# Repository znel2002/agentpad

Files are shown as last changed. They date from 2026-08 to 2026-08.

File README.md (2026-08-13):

# AgentPad

A 9-key macropad + rotary encoder + OLED for driving **AI coding agents** — Claude Code, Codex CLI, and Cursor. Firmware-native (no host daemon), vendor-neutral, with a per-tool **LAYER** key instead of app-detection. Built for **Hack Club Hackpad**.

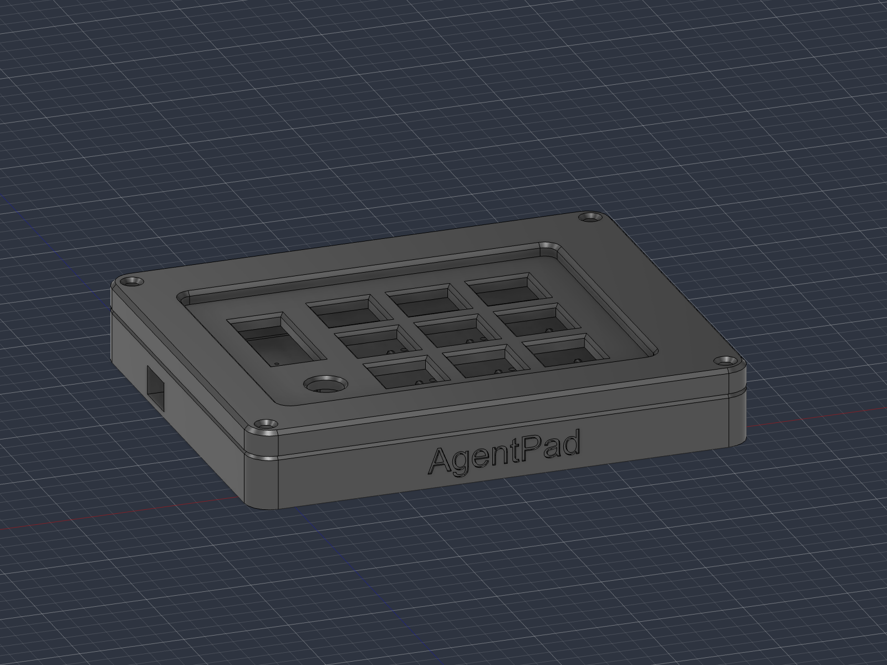
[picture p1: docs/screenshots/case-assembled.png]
AgentPad — real PCB in the 3D-printed case


## What it does

Nine keys mapped to the actions you hit dozens of times an hour when driving an agent, plus a rotary dial and a status screen:

| | | |
|---|---|---|
| **STOP** (interrupt) | **YES** (approve) | **NO** (reject) |
| **PLAN** (mode toggle) | **NEW** (`/clear`) | **TALK** (push-to-talk) |
| **RUN** (test/last cmd) | **COMPACT** (`/compact`) | **LAYER** (switch tool) |

- **Encoder** — turn = model / reasoning-effort dial.
- **OLED** — shows the active tool profile + mode.
- **LAYER key** — cycles per-tool keymaps: **Claude Code → Codex → Cursor → shell**. Each key sends that tool's real shortcut; hold-LAYER reaches secondary actions (accept-edit, reject-edit, resume, background). No daemon, no app-detection.

Full keymap + pin map: [docs/DESIGN-SPEC.md](docs/DESIGN-SPEC.md). Keymap logic is unit-tested: [Firmware/tests/sim_keymap.py](Firmware/tests/sim_keymap.py).

## Hardware

- **MCU:** Seeed XIAO RP2040 (all 11 GPIO used)
- **Keys:** 9× MX in a 3×3 diode matrix (9× 1N4148, COL2ROW)
- **Encoder:** 1× EC11 (turn-only)
- **Display:** 1× 0.91" SSD1306 OLED (I2C)
- **Firmware:** KMK (CircuitPython)
- **RGB:** deferred to v2 (v1 ships without LEDs)

## Renders & proof

**Exploded — top plate / PCB / bottom tray**
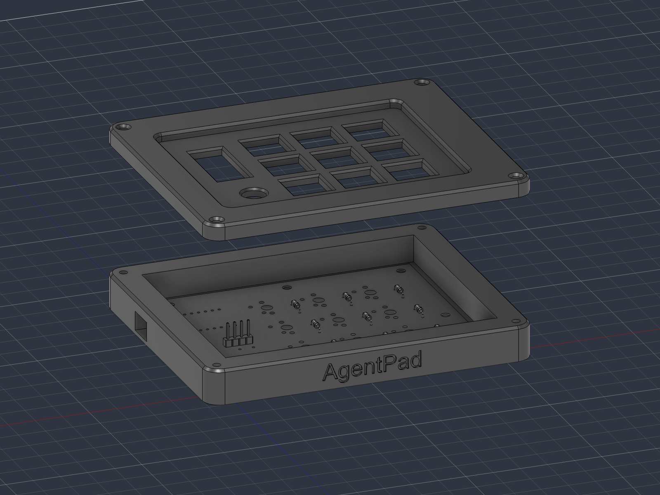
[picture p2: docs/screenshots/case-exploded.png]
Exploded assembly


**Schematic**
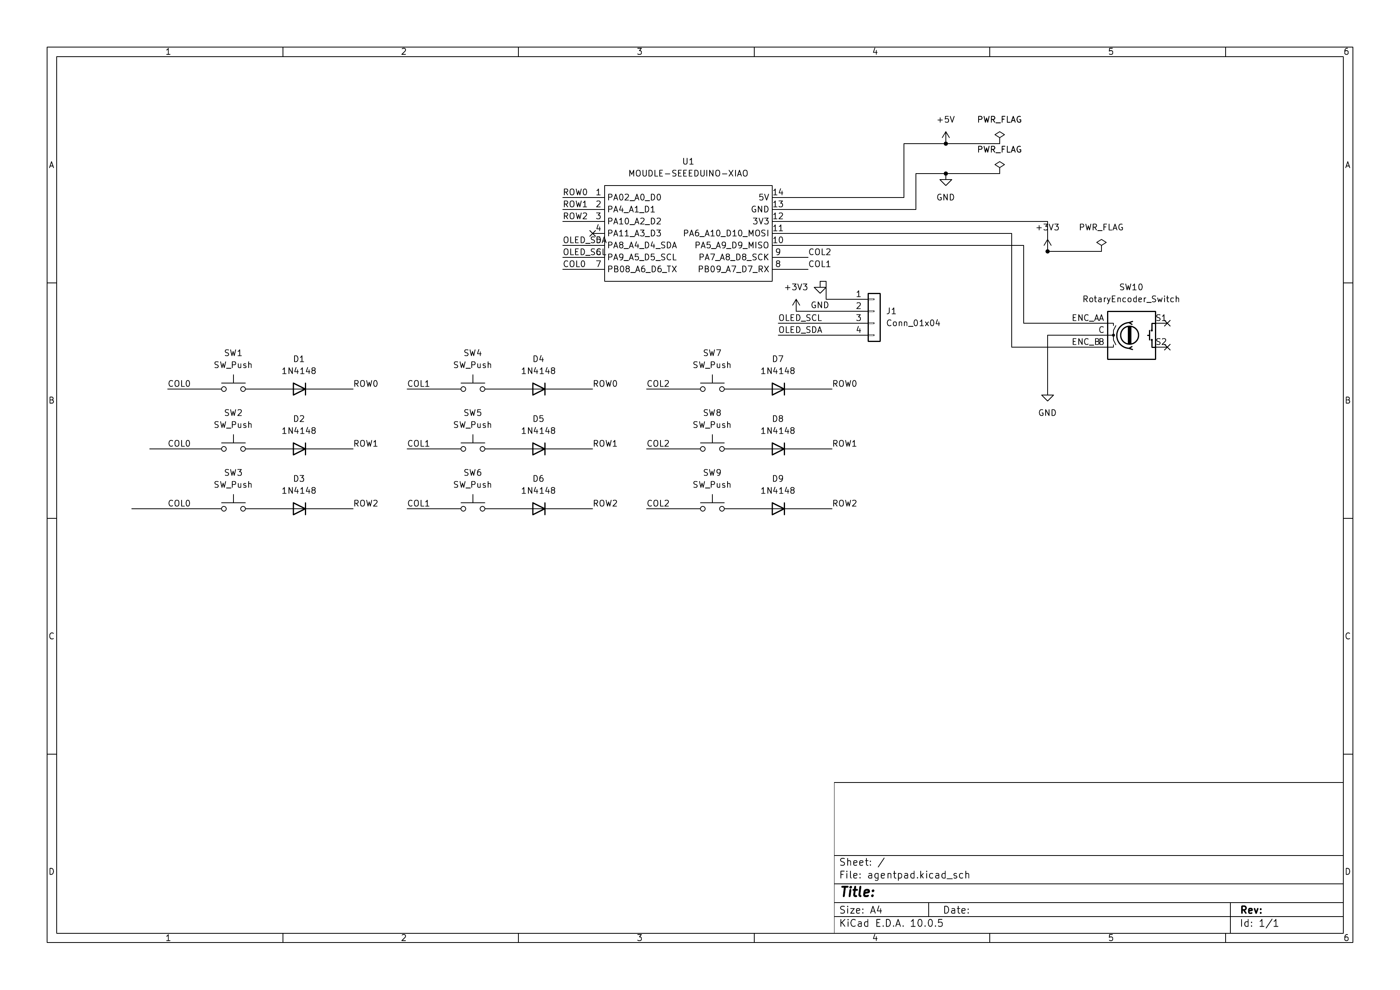
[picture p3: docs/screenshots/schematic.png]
Schematic


**PCB — DRC passes with 0 errors**
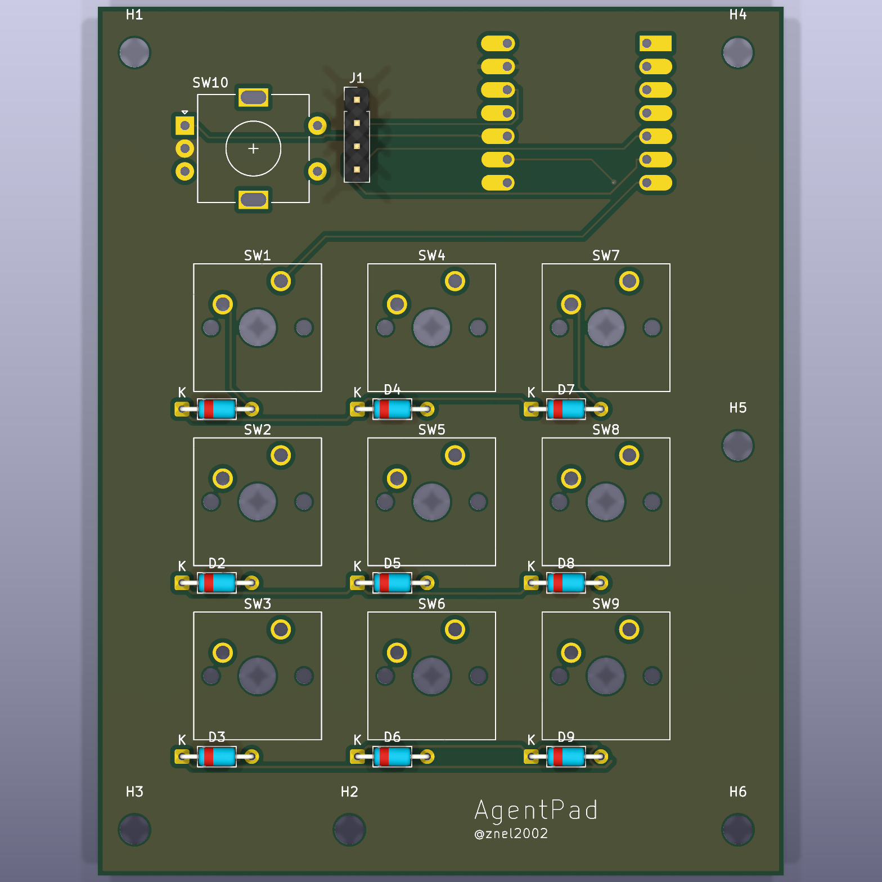
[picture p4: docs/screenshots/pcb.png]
PCB


## Bill of Materials

All parts come from the free Hackpad kit (nothing self-sourced):

| Part | Qty | Notes |
|---|---|---|
| Seeed XIAO RP2040 | 1 | microcontroller |
| 1N4148 diode | 9 | switch matrix, COL2ROW, `D_DO-35_SOD27_P7.62mm` |
| MX-style switch | 9 | solder-in, 3×3 grid @ 19.05 mm |
| EC11 rotary encoder | 1 | model / effort dial |
| 0.91" OLED (SSD1306) | 1 | I2C, pin order GND-VCC-SCL-SDA |
| DSA blank keycap | 9 | color/legend via a printed card |
| M3 screw | 4 | lid → base corner posts |

## Repo structure

```
CAD/         agentpad-case.f3d (Fusion source), agentpad_assembly.step/.3mf (case + real PCB), board STEP
PCB/         KiCad project — schematic, board (DRC 0 errors), Hack Club care-package libs
Firmware/    KMK source (kmk/main.py) + keymap simulation test
production/  gerbers.zip, top_plate.stl, bottom_tray.stl, main.py
docs/        DESIGN-SPEC, BUILD-PLAN, screenshots
```

## Firmware (KMK)

Flash CircuitPython to the XIAO, copy the KMK `kmk/` folder + libs + [`Firmware/kmk/main.py`](Firmware/kmk/main.py) to the `CIRCUITPY` drive. Details + per-layer keystroke tables: [Firmware/README.md](Firmware/README.md).

## Case

3D-printed two-part sandwich — **top lid + bottom base** — designed in **Autodesk Fusion** ([CAD/agentpad-case.f3d](CAD/agentpad-case.f3d)) around the exact PCB (imported as STEP). Both parts print flat with no supports.

- **Lid:** recessed key well inside a raised bezel; 9 switch cutouts with chamfered mouths, an encoder hole, and an OLED window; rounded R6 corners.
- **Base:** holds the PCB on corner posts; USB-C exits a slot in the side wall; **AgentPad** engraved on the front wall; matching R6 corners and chamfered top edge.
- **Assembly:** 4× M3 screws through the lid into the base's corner posts.

Fit is verified against the real board geometry — switch cutouts sit exactly on the switch stems, and screw holes align to the base bosses.

## License

MIT — see notes; the vendored Hack Club care package under `PCB/lib/` retains its own license.

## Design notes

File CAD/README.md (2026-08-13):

# CAD — AgentPad case

Two-part 3D-printed sandwich (top lid + bottom base), designed in **Autodesk Fusion**
around the exact PCB. The board is imported as STEP and every cutout is placed on the
real switch/encoder/OLED/mounting geometry.

## Files
- `agentpad-case.f3d` — Fusion source (editable), the case + inserted PCB reference.
- `agentpad_assembly.step` / `agentpad_assembly.3mf` — full assembly (case + real PCB).
- `agentpad-board.step` — the KiCad board export.
- `agentpad-board-origin.step` — the same board parked at the origin (used as the Fusion import reference).
- Printable parts live in [`../production/`](../production/): `top_plate.stl` (lid), `bottom_tray.stl` (base).

## Design
- **Outer size:** 120 × 100 mm (both parts match). Rounded corners R6.
- **Lid:** 3 mm plate + 4 mm raised bezel around a recessed key well. 9× 14 mm switch
  cutouts with chamfered mouths, Ø8.5 encoder hole, OLED window, 4× M3 clearance holes.
- **Base:** ~13 mm tall tray holding the PCB; USB-C slot in the side wall; `AgentPad`
  engraved on the front wall; 4 corner posts for the screws.
- **Assembly:** 4× M3 screws, lid → base corner posts.

## Print notes
- Both parts print flat, **no supports**.
- Print tolerance ~0.2 mm between mating parts.
- **Verify before printing** (physical modules): the OLED window and USB-C opening
  size/position, and the encoder hole diameter vs your knob.

## Hard limits
- Case ≤ **200 × 200 × 100 mm**, **3D-printed only** (no laser/acrylic parts). ✔

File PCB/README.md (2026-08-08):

# PCB — AgentPad

KiCad source for the AgentPad board. Design locked in
[../docs/DESIGN-SPEC.md](../docs/DESIGN-SPEC.md).

## Before you start
1. KiCad **10.0.5** is installed. Its libraries are forward-compatible, so the
   care package (authored on an older version) loads fine — no version issue.
2. Download + install the libraries here:
   - **Care package** (XIAO symbol + footprints): https://github.com/hackclub/hackpad/releases/tag/v0.1-bugfix → `kicad_care_package.zip`
   - XIAO footprints (backup): https://github.com/Seeed-Studio/OPL_Kicad_Library
   - MX switch footprints: https://github.com/ai03-2725/MX_V2
   - Rotary encoder: https://kicad.github.io/footprints/Rotary_Encoder
   - 0.91" OLED (4-pin): https://github.com/gorbachev/KiCad-SSD1306-0.91-OLED-4pin-128x32.pretty
   - The `.sym` files are symbol libs; the `.pretty` folders are footprint libs
     (Preferences → Manage Symbol/Footprint Libraries → add).
3. **Reference board** — the guide author's macropad (OLED + encoder + matrix +
   SK6812, closest to ours): https://github.com/hackclub/hackpad/tree/clean/extras/orpheuspad
4. Learn the flow: ai03's PCB guide https://wiki.ai03.com/books/pcb-design
5. Build the 3-key tutorial board first (XIAO symbol = `MODULE-SEEEDUINO-XIAO`,
   switches = `SW_Push`) to validate the toolchain, then extend to this net map.

## Net map — XIAO RP2040 pad → net (all 11 GPIO used)

| Pad | GPIO | Net |
|---|---|---|
| D0 | GP26 | ROW0 |
| D1 | GP27 | ROW1 |
| D2 | GP28 | ROW2 |
| D3 | GP29 | LED_DIN (SK6812 chain data-in) |
| D4 | GP6 | OLED_SDA (I2C) |
| D5 | GP7 | OLED_SCL (I2C) |
| D6 | GP0 | COL0 |
| D7 | GP1 | COL1 |
| D8 | GP2 | COL2 |
| D9 | GP4 | ENC_A |
| D10 | GP3 | ENC_B |
| 3V3 | — | OLED VCC |
| **5V** | — | **all SK6812 VCC** (the LEDs are 5V parts, per the Hackpad add-components page) |
| GND | — | matrix/encoder commons, OLED GND, all SK6812 GND |

> Data logic stays at the XIAO's 3.3V; SK6812 run their VCC at 5V (the XIAO's 5V/USB
> pad). This is how the kit is designed — do not put SK6812 VCC on 3V3.

## Exact symbols / footprints (confirmed on hackpad.hackclub.com/add-components)

Verified against the unpacked care package in `lib/kicad_care_package/`. The care
package holds **only** the XIAO + SK6812; everything else is a KiCad built-in lib.

| Part | Symbol | Footprint | Source |
|---|---|---|---|
| XIAO RP2040 | `MOUDLE-SEEEDUINO-XIAO` *(sic — typo is in the file, search it literally)* | `XIAO-Generic-Hybrid-14P-2.54-21X17.8MM` | care package |
| SK6812 MINI-E | `SK6812MINI-E` | `SK6812MINI-E_fixed` | care package |
| MX switch | `SW_Push` | `ai03-2725/MX_V2` (or KiCad `Button_Switch_Keyboard`) | KiCad / MX_V2 |
| Diode 1N4148 | `D` | `Diode_THT:D_DO-35_SOD27_P7.62mm_Horizontal` (don't go shorter) | KiCad built-in |
| EC11 encoder | `RotaryEncoder_Switch` | `RotaryEncoder_Alps_EC11E-Switch_Vertical_H20mm` | KiCad built-in |
| 0.91" OLED | 4-pin header (`Connector_Generic`) | `PinHeader_1x04_P2.54mm_Vertical` | KiCad built-in |

No pull-up resistors anywhere — the RP2040 has internal pull-ups (kit relies on this).

## Matrix (3×3, 9 keys)
- One **1N4148** (onsemi) per key, all the **same orientation (COL2ROW)**. Wrong
  diode direction is the #1 beginner failure — verify against the KMK config
  (`Firmware/kmk/main.py`, `diode_orientation = COL2ROW`). The physical diode has
  a **black bar** marking the cathode.
- Footprint `Diode_THT:D_DO-35_SOD27_P7.62mm_Horizontal`.
- Keys map row-major to the keymap: R1C1..R1C3, R2C1..R2C3, R3C1..R3C3.

## Encoder (EC11E, 20 mm D-shaft)
- Symbol `RotaryEncoder_Switch`, footprint `RotaryEncoder_Alps_EC11E-Switch_Vertical_H20mm`.
- A → ENC_A (D9), B → ENC_B (D10), common → GND. No pull-ups needed.
- **Turn-only config:** the footprint includes the push-switch pins — leave them
  **unconnected**. Keeping the pads means an 8-key clickable variant is possible
  later without a respin.

## OLED (0.91" 128×32 SSD1306, I2C @ 0x3C)
- Footprint = plain **2.54 mm 4-pin header** (the module has a standard header;
  no special footprint needed).
- **Pin order GND-VCC-SCL-SDA** — match it exactly (online pinouts vary).
- SDA→D4, SCL→D5, VCC→3V3, GND→GND. No pull-ups needed.

## SK6812 MINI-E chain (20 LEDs, 1 data line)
- Footprint `SK6812MINI-E` from the care package (**not** `SK6812MINI`; symbol +
  both footprints must say MINI-E).
- 4 pins: VCC (**5V**), GND, DIN, DOUT. D3 → LED1 DIN; each DOUT → next DIN; chain all 20.
- **Orientation: the notch/cut is on the bottom-right corner** — wrong rotation and
  the LEDs won't light. Keep every LED the same way.
- 9 per-key (under each switch) + up to 11 case underglow.
- Keep the data trace from the XIAO to LED1 short.

## Mounting holes (from the Hackpad resources page)
- Use KiCad's **M3 mounting-hole footprint** — NOT Edge.Cuts.
- 6 holes to match the 6× M3 screws / heatset inserts.
- For the OLED, a plain **4-pin header footprint** is fine (order GND-VCC-SCL-SDA).

## Routing tips (from the resources page)
- Try to route everything on **one layer** first; only drop to the 2nd layer to
  avoid a big loop. Keeps the board clean.
- After routing: **Tools → Cleanup Tracks & Vias** (press "Build changes" twice).
- Export the PCB to PDF and print 1:1 to sanity-check physical measurements.

## Preflight before ordering
- [ ] Board ≤ 100 × 100 mm, **2 layers**.
- [ ] `AgentPad` on the silkscreen.
- [ ] 6× M3 mounting-hole footprints placed.
- [ ] **DRC → 0 errors** (reviewers check this).
- [ ] Export gerbers → `../production/gerbers.zip`.
- [ ] Order JLCPCB immediately after DRC is clean.

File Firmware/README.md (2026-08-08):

# Firmware — AgentPad (KMK)

KMK (CircuitPython) firmware. Keymap + pin map locked in
[../docs/DESIGN-SPEC.md](../docs/DESIGN-SPEC.md). Entry point: [kmk/main.py](kmk/main.py).

## Flash setup (XIAO RP2040)
1. **CircuitPython:** double-tap the XIAO reset to enter bootloader (RPI-RP2
   drive), drop the CircuitPython `.uf2` for the Seeed XIAO RP2040
   (https://circuitpython.org/board/seeeduino_xiao_rp2040/). It reboots as a
   `CIRCUITPY` drive.
2. **KMK:** clone https://github.com/KMKfw/kmk_firmware and copy its `kmk/`
   folder to `CIRCUITPY/`.
3. **Libraries** (into `CIRCUITPY/lib/`, from the Adafruit CircuitPython bundle):
   - `neopixel.mpy` — per-key RGB
   - `adafruit_displayio_ssd1306.mpy` + `adafruit_display_text/` — OLED
     (displayio is built into CircuitPython on RP2040)
4. Copy [kmk/main.py](kmk/main.py) to `CIRCUITPY/main.py`. It runs on boot.

## Test order (before the PCB arrives)
Breadboard the XIAO and validate incrementally — comment out blocks in `main.py`:
1. Matrix scan (press a key across a row/col jumper → keystroke appears).
2. Encoder turn.
3. One SK6812 lights.
4. OLED prints text.

## Status
- Matrix, encoder, layers, hold-LAYER FN, static per-key RGB, OLED splash: scaffolded.
- **TODO:** finalize Codex / Cursor / shell keystrokes; verify the layer-cycle key
  on your KMK version (see the comment in `main.py`); optional live LED feedback.

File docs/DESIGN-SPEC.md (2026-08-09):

# AgentPad — Hardware & UX Design Spec (v1)

Status: **v1 PCB complete, DRC 0 errors.** This is the buildable design the PCB,
case, and firmware are cut from.

> **v1 ships without RGB LEDs.** The SK6812 reverse-mount footprint (with its
> built-in board cutout) could not pass edge-clearance DRC, and RGB is not
> required by Hackpad (the reference board barely used LEDs). v1 = 9 switches +
> encoder + OLED. **RGB (per-key / underglow) is deferred to v2** with a proper
> LED footprint.

---

## 1. Locked decisions

| Decision | Value | Why |
|---|---|---|
| Name (branding) | **AgentPad** | On PCB silkscreen + top plate (Hackpad requires it) |
| MCU | Seeed XIAO RP2040 | Required by Hackpad; **11 usable GPIO** is the binding constraint |
| Config | **9 keys (3×3) + 1 EC11 encoder + 0.91" OLED + SK6812 RGB** | Only kit-only config that keeps screen + dial + per-key RGB |
| Encoder | **1, turn-only** (effort/model dial, live-apply) | 2nd encoder would force dropping the OLED; click would cost the 9th key |
| Firmware | **KMK** (CircuitPython) first, QMK fallback | Fastest iteration for a Python dev; no compile step |
| Tool layers | **4**: Claude Code · Codex · Cursor · shell | Vendor-neutral is the whole differentiator |
| PCB | 2-layer, ≤100×100 mm, **green** soldermask | Cheapest/fastest fab; DRC must pass 0 errors |
| Legends | **RGB color-coding + printed legend card** | Kit ships blank DSA caps; color is the legend |
| Case | 3D-printed sandwich, 6× M3 into heatset inserts, ≤200×200×100 mm | Kit + rules |

---

## 2. Pin budget (all 11 GPIO used)

RGB chains on one data wire regardless of LED count, so it costs 1 pin for all
20 LEDs. The rest divides as:

| Function | Pins | XIAO pads |
|---|---|---|
| Key matrix 3×3 (3 rows + 3 cols) | 6 | rows D0/D1/D2 (GP26/27/28), cols D6/D7/D8 (GP0/1/2) |
| Encoder A/B | 2 | D9/D10 (GP4/GP3) |
| OLED I2C (SDA/SCL) | 2 | D4/D5 (GP6/GP7) |
| SK6812 RGB data | 1 | D3 (GP29) |
| **Total** | **11** | D0–D10 fully allocated |

- Matrix diode direction: one 1N4148 per key (9 used of 20). Pick **COL2ROW** and
  keep every diode the same orientation (the #1 beginner failure). Confirm the
  direction against the KMK/QMK matrix config before ordering.
- OLED footprint pin order is **GND-VCC-SCL-SDA** (kit spec) — the PCB must match.
- Encoder is turn-only in this config (no matrix node free for the push). A
  clickable encoder is available only by dropping to 8 keys.

---

## 3. Keymap

9 physical keys in a fixed 3×3 grid. Each **layer** = one tool profile; the same
key sends that tool's equivalent keystroke. The Claude Code column is the
reference binding; the other three fill the same slots (finalized against each
tool's current shortcuts at firmware time).

| Pos | Key | Purpose | Claude Code keystroke |
|---|---|---|---|
| R1C1 | **STOP** | Interrupt the run, don't kill the session | `Esc` |
| R1C2 | **YES** | Approve / accept the pending prompt | `Enter` |
| R1C3 | **NO** | Reject / decline | `n` |
| R2C1 | **PLAN** | Cycle permission / plan mode | `Shift+Tab` |
| R2C2 | **NEW** | Clear context, fresh session | `/clear⏎` |
| R2C3 | **TALK** | Push-to-talk dictation (momentary, active while held) | hold `Space` |
| R3C1 | **RUN** | Fire test / last command | `npm test⏎` (configurable) |
| R3C2 | **COMPACT** | Compact the context window | `/compact⏎` |
| R3C3 | **LAYER** | **Tap** = cycle tool profile · **Hold** = FN modifier | — |

**Encoder:** turn = reasoning-effort / model dial, applies live; OLED shows the
new level.

**Hold-LAYER secondary actions** (recover the Tier-2/3 actions without more keys):
- Hold LAYER + **YES** = accept edit/diff
- Hold LAYER + **NO** = reject edit/diff
- Hold LAYER + **NEW** = resume session (`/resume⏎`)
- Hold LAYER + **RUN** = background task

Per-layer keystroke tables (Codex / Cursor / shell) → firmware appendix, TBD.

---

## 4. RGB scheme (20× SK6812, 1 data pin)

9 per-key LEDs + up to 11 case-underglow LEDs on the same chain (0 extra pins).

**Static per-key function color** (the legend):

| STOP 🔴 red | YES 🟢 green | NO 🟠 amber |
|---|---|---|
| **PLAN 🔵 blue** | **NEW 🟣 purple** | **TALK 🩵 cyan** (brightens while held) |
| **RUN ⚪ white** | **COMPACT teal** | **LAYER = active-tool color** |

**Layer identity** (LAYER key + underglow wash): Claude Code = amber · Codex =
green · Cursor = blue · shell = white.

**Feedback:** brief flash on key press.

Offline note: RGB encodes *local* state (layer, function, press). Live agent
status (idle/thinking/waiting) needs optional USB-serial feedback from the host —
**parked as a post-submission stretch.**

---

## 5. OLED (0.91", 128×32, SSD1306)

- Line 1: active tool profile — `CLAUDE CODE`
- Line 2: effort + mode — `effort: HIGH  ·  PLAN`
- Boot splash: `AgentPad` + logo.

Same offline caveat: the mode field tracks local PLAN/effort presses, it does not
read the host.

---

## 6. Physical layout

- 3×3 key grid on **19.05 mm** MX spacing. OLED top-left, encoder top-right on the
  strip above the grid. Estimated footprint ~70×90 mm (inside 100×100 mm).
- MX switches are **solder-in** (no hotswap sockets in kit).
- Sandwich case: top plate + PCB + bottom, 6× M3×16 screws into M3 heatset inserts.
- `AgentPad` branding on the top plate (recessed/embossed) **and** PCB silkscreen.
- Printed legend card / plate silkscreen keying the RGB colors to functions.

---

## 7. Open items before layout
- [ ] **Germany shipping** — ships from Burlington VT; the site never addresses
      international shipping. Confirm in #hackpad (the one real unknown).
- [ ] **Grant amount conflict** — the submitting page says **$15** for the PCB, the
      FAQ says **$10**. Confirm the current number in #hackpad. (Iron grant is $18,
      non-transferrable, both pages agree.)
- [ ] Confirm the kit's MX switch type (tactile vs linear) in #hackpad.
- [ ] Finalize Codex / Cursor / shell per-layer keystroke tables.
- [ ] Decide 9-key-turn-only vs 8-key-clickable-encoder (default: 9-key).
- [ ] Case color (decide at print time with Printing Legion).

---

## 8. Bill of materials (from the free kit)

| Part | Qty used / kit | Notes |
|---|---|---|
| Seeed XIAO RP2040 | 1 / 1 | |
| 1N4148 diode | 9 / 20 | one per key, COL2ROW |
| MX-style switch | 9 / 16 | solder-in |
| EC11 encoder | 1 / 2 | 2nd = solder backup |
| 0.91" OLED (SSD1306) | 1 / 1 | GND-VCC-SCL-SDA |
| SK6812 MINI-E LED | up to 20 / 20 | 9 per-key + underglow |
| DSA blank keycap | 9 / 16 | color-coded |
| M3×16 screw | 6 / 6 | |
| M3 heatset insert | 6 / 6 | |

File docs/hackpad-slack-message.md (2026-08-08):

# Draft message for #hackpad

Post this after joining. Confirms the three things public pages couldn't nail.
Edit the tone to taste.

---

> Hey! Starting a Hackpad build (a 9-key + encoder + OLED macropad for driving AI
> coding CLIs, XIAO RP2040, KMK). Three quick confirmations before I order a PCB:
>
> 1. **Shipping to Germany** 🇩🇪 — is the parts kit shipped to the EU/Germany, and is
>    the $15 PCB card-grant path available here?
> 2. **Grant amounts** — are the current grants $15 for the PCB and $18 for a
>    soldering iron? (FAQ still says $10 in one spot.)
> 3. **MX switches** — what switch type ships in the kit (tactile / linear /
>    clicky), so I can plan the feel?
>
> Thanks!

---

Record the answers in `docs/DESIGN-SPEC.md` §7 when they come back.

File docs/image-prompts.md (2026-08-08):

# Showcase image prompts (Gemini "Nano Banana" / 2.5 Flash Image)

For the README hero + ship post. Generate 3-4, pick the cleanest (OLED text,
screw count, and keycap spelling vary run to run). Top-down angles render the
keycap legends most reliably.

## Hero shot (with keycap legends)

```text
Professional product-showcase render of a custom mechanical macropad called
"AgentPad", a compact desktop keypad for controlling AI coding assistants.

FORM FACTOR: a small sandwich-style macropad, roughly 70 x 90 mm, made of a
3D-printed matte case (top plate + body) with a visible green PCB edge. Six small
M3 hex screws recessed into the top plate corners and mid-edges. Clean, minimal,
premium build quality.

TOP CONTROL STRIP (above the keys): on the LEFT a small 0.91-inch monochrome OLED
display (wide, short, blue-on-black) showing two crisp lines of text:
"CLAUDE CODE" on the first line and "effort: HIGH" on the second line. On the
RIGHT a knurled aluminium rotary encoder knob.

KEY LAYOUT: a 3x3 grid of nine white DSA-profile keycaps, evenly spaced on
19.05 mm pitch. Each cap has a short label printed in the center in a clean bold
black uppercase sans-serif font, and each key is lit from beneath by a per-key
RGB LED so the cap glows a distinct color. The nine keys, left-to-right and
top-to-bottom, are:
- Row 1: "STOP" glowing red, "YES" glowing green, "NO" glowing amber
- Row 2: "PLAN" glowing blue, "NEW" glowing purple, "TALK" glowing cyan
- Row 3: "RUN" glowing white, "COMPACT" glowing teal, "LAYER" glowing warm amber
All labels must be spelled exactly as written, correct spelling, legible and sharp.
A soft RGB underglow spills from beneath the case onto the surface below.

BRANDING: the word "AgentPad" printed cleanly in a modern sans-serif on the top
plate along the front edge, subtle and legible.

SCENE: three-quarter hero angle, slightly above eye level, on a dark matte desk
surface with a softly blurred dark studio background. Cinematic soft key light
with gentle rim lighting, realistic reflections on the keycaps and knob, shallow
depth of field, high detail, 4k product photography, sharp focus on the pad.

STYLE: clean tech-product marketing render, like a premium keyboard brand's
website hero image. Photorealistic. No hands, no extra objects, no clutter.

Aspect ratio 16:9.
```

## Variants
- **Top-down flat lay** (best for legible legends): replace the SCENE paragraph with
  `perfectly top-down flat-lay view, centered, even soft lighting, dark textured desk, aspect ratio 1:1.`
- **Lifestyle:** replace SCENE with `on a developer's wooden desk beside a glowing monitor showing a code terminal, warm ambient evening light, bokeh background, aspect ratio 16:9.`
- **Exploded view:** add `shown as an exploded assembly diagram with the top plate, keycaps, PCB, and bottom case floating apart in stacked layers.`

## Fixups
- Fake letters on caps? add `blank keycaps with no letters` (or keep the labeled version).
- Long word breaking? shorten `COMPACT` -> `CMPCT` in the prompt.
- Iterate: feed the winner back with "same macropad, keep the green PCB and
  color-coded labeled keys, now show it from a lower front angle."

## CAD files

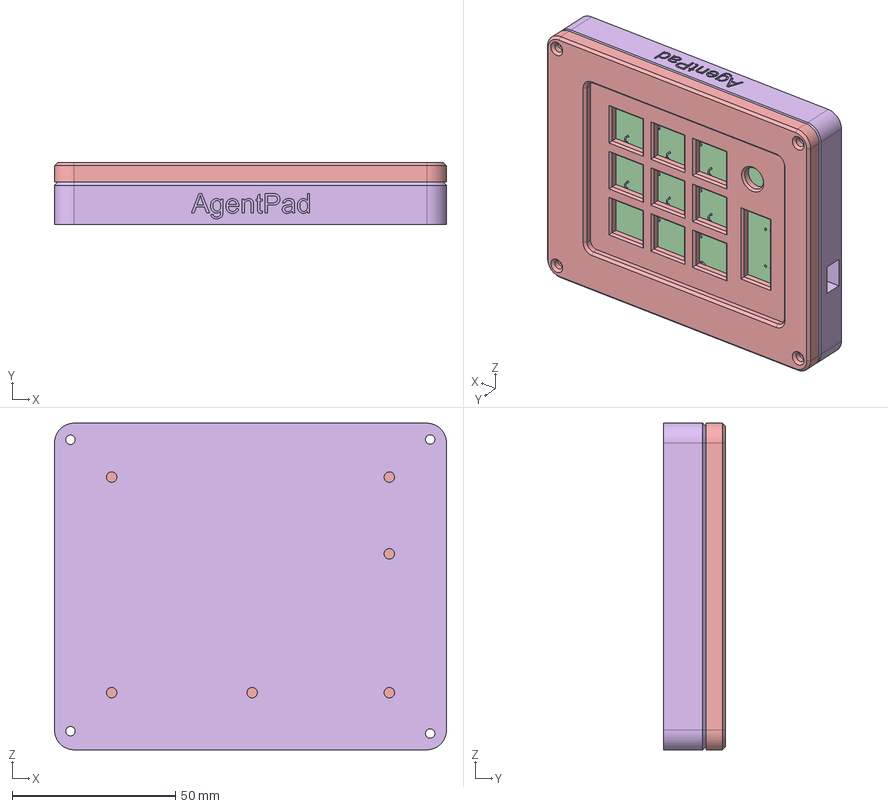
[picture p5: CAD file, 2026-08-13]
CAD/agentpad_assembly.step
120.0 x 19.0 x 100.0 mm

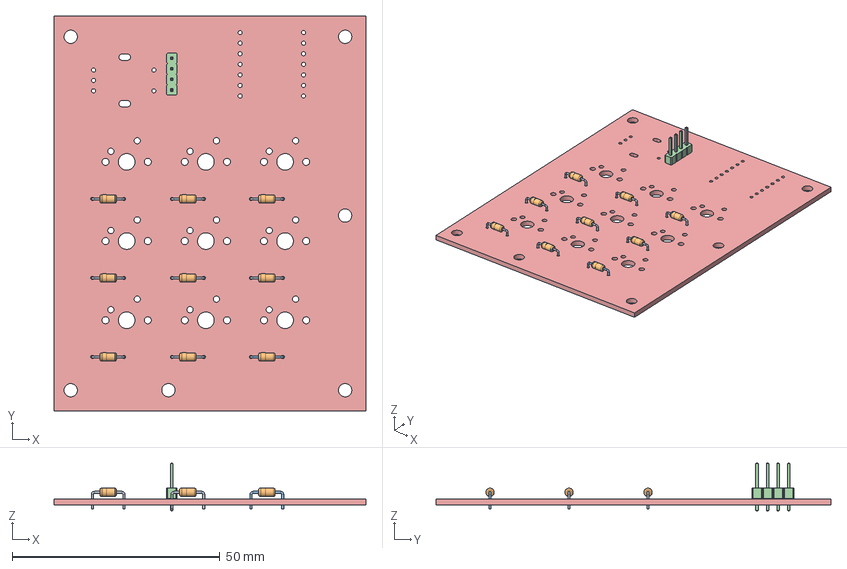
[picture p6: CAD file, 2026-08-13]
CAD/agentpad-board-origin.step
75.0 x 95.0 x 11.5 mm

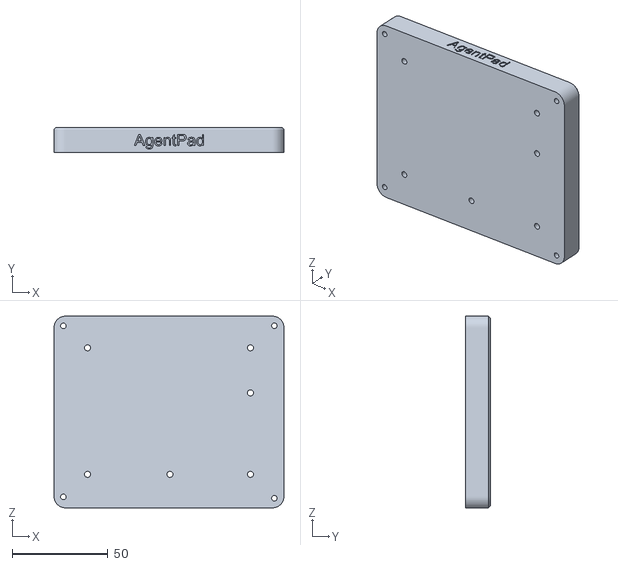
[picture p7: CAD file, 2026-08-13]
production/bottom_tray.stl
120.0 x 13.0 x 100.0

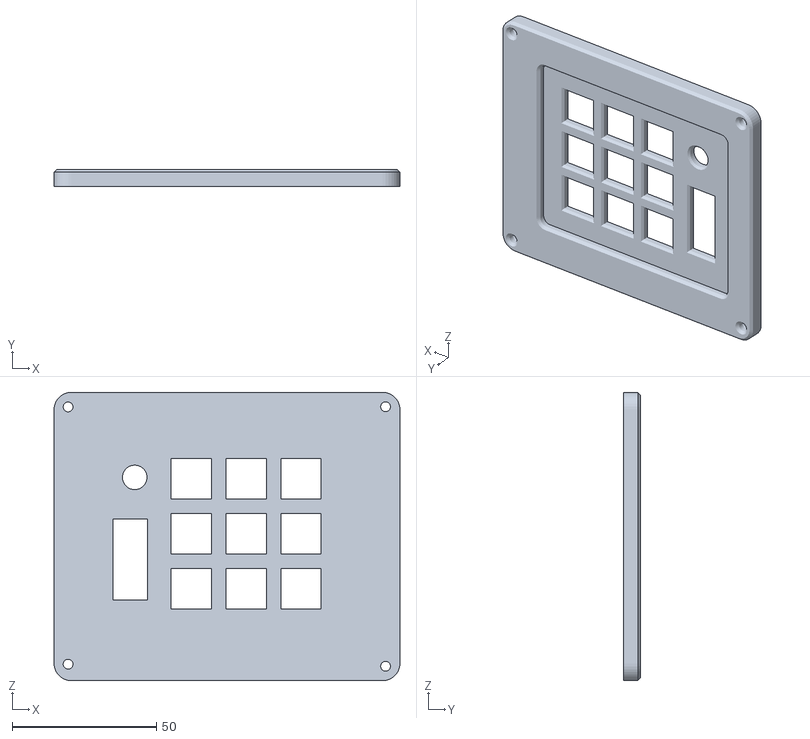
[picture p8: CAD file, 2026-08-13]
production/top_plate.stl
120.0 x 6.00 x 100.0

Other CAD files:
CAD/agentpad-board.step
CAD/agentpad-case.f3d
CAD/agentpad_assembly.3mf

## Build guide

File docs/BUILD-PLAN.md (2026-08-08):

# AgentPad — Build Plan

The shortest path from here to a submitted Hackpad board. Design is locked in
[DESIGN-SPEC.md](DESIGN-SPEC.md). Check boxes as you go.

## Session 0 — admin (do first, runs in parallel with everything)
- [ ] Join **#hackpad** on Hack Club Slack.
- [ ] Post the confirmation message ([docs/hackpad-slack-message.md](hackpad-slack-message.md)):
      Germany shipping, current grant amounts, MX switch type.
- [ ] Note the answers back into DESIGN-SPEC.md §7.

## Session 1 — toolchain validation
- [ ] Install KiCad (stable — 8.x or 9.x, whatever the guide + care package target;
      confirm the version in #hackpad before committing to KiCad 10).
      `brew install --cask kicad`  *(may prompt for your password)*
- [ ] Grab Hack Club's footprint/symbol **care package** (XIAO RP2040 + SK6812)
      from the guide → drop into `PCB/`. Links in [PCB/README.md](../PCB/README.md).
- [ ] Build the official **3-key tutorial board** end to end (schematic → route →
      DRC 0 → gerbers). This proves the toolchain before the real layout.

## Session 2 — the AgentPad PCB
- [ ] Schematic: XIAO + 3×3 matrix (9 switches + 9 diodes) + encoder + OLED header +
      20× SK6812 chain, wired per the net map in [PCB/README.md](../PCB/README.md).
- [ ] Footprints: use care-package parts. **OLED pin order GND-VCC-SCL-SDA.**
      **All diodes same orientation (COL2ROW).**
- [ ] Route (2 layers, ≤100×100 mm), add `AgentPad` silkscreen.
- [ ] **DRC → 0 errors.** Do not order until this is clean.
- [ ] Export gerbers → `production/gerbers.zip`.
- [ ] **Order from JLCPCB the moment DRC is clean** so fab/ship overlaps case + firmware.

## Session 3 — firmware (can start before boards arrive)
- [ ] Flash CircuitPython to the XIAO RP2040.
- [ ] Copy KMK + libs + [Firmware/kmk/main.py](../Firmware/kmk/main.py) to CIRCUITPY.
      Setup in [Firmware/README.md](../Firmware/README.md).
- [ ] Breadboard-test the matrix scan + encoder + OLED + one LED before the PCB lands.
- [ ] Fill in the Codex / Cursor / shell per-layer keystroke tables.

## Session 4 — case
- [ ] Generate the switch plate with the ai03 plate generator (3×3, 19.05 mm).
- [ ] Fusion 360 sandwich case (top plate + body), 6× M3 + heatset bosses,
      `AgentPad` on the top plate, 0.2–0.25 mm mating tolerances, no-supports print.
- [ ] Export one STEP/3MF of the assembly → `CAD/`; per-part STL/STEP → `production/`.

## Session 5 — assemble + ship
Assembly order matters (from hackpad.hackclub.com/assembly):
- [ ] Solder **diodes first** — the black bar marks the cathode; match COL2ROW.
      Clip the legs after.
- [ ] **Clip switches into the plate BEFORE soldering them to the PCB** (don't skip).
- [ ] Solder the XIAO, encoder, OLED header, SK6812s (watch the notch orientation).
- [ ] Run an **electrical test** before closing the case.
- [ ] Assemble the sandwich; flash firmware.
- [ ] production/: `gerbers.zip`, per-part case STL/STEP, and **`main.py`** (KMK needs
      no `.uf2` — the source file is the deliverable).
- [ ] README screenshots (all required): overall render + schematic + PCB + case-fit + BOM.
- [ ] Ship post in **#hackpad-ships** (name / repo / description / images), submit the form.
- [ ] After approval + build: submit for a **serial number**.

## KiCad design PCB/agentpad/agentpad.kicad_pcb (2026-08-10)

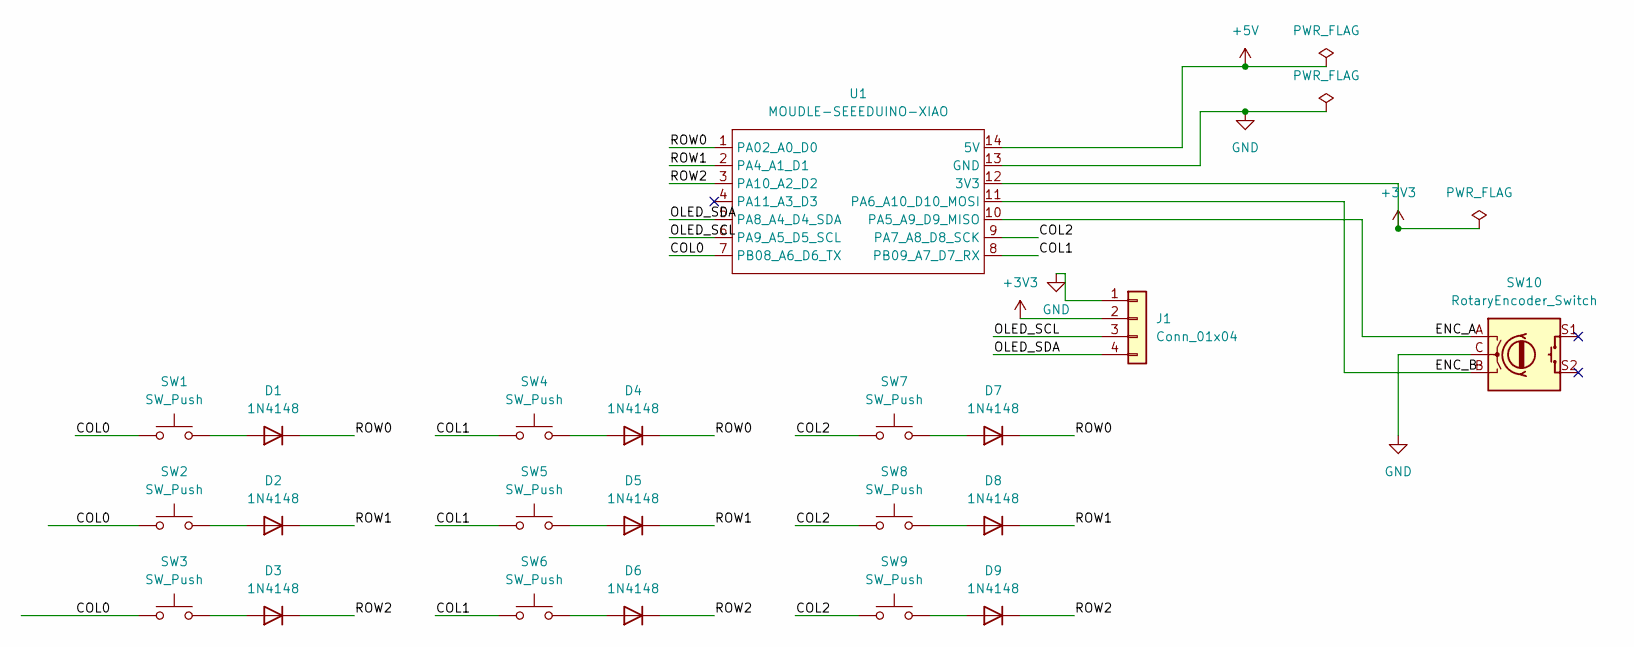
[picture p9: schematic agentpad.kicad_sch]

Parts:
D1, D2, D3, D4, D5, D6, D7, D8, D9: 1N4148; D_DO-35_SOD27_P7.62mm_Horizontal
J1: Conn_01x04; PinHeader_1x04_P2.54mm_Vertical
SW1, SW2, SW3, SW4, SW5, SW6, SW7, SW8, SW9: SW_Push; SW_Cherry_MX_1.00u_PCB
SW10: RotaryEncoder_Switch; RotaryEncoder_Alps_EC11E-Switch_Vertical_H20mm
U1: MOUDLE-SEEEDUINO-XIAO; XIAO-Generic-Hybrid-14P-2.54-21X17.8MM

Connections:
+3V3: J1.2, U1.12 (3V3)
+5V: U1.14 (5V)
/COL0: SW1.1, SW2.1, SW3.1, U1.7 (PB08_A6_D6_TX)
/COL1: SW4.1, SW5.1, SW6.1, U1.8 (PB09_A7_D7_RX)
/COL2: SW7.1, SW8.1, SW9.1, U1.9 (PA7_A8_D8_SCK)
/ENC_A: SW10.A, U1.10 (PA5_A9_D9_MISO)
/ENC_B: SW10.B, U1.11 (PA6_A10_D10_MOSI)
/OLED_SCL: J1.3, U1.6 (PA9_A5_D5_SCL)
/OLED_SDA: J1.4, U1.5 (PA8_A4_D4_SDA)
/ROW0: D1.1 (K), D4.1 (K), D7.1 (K), U1.1 (PA02_A0_D0)
/ROW1: D2.1 (K), D5.1 (K), D8.1 (K), U1.2 (PA4_A1_D1)
/ROW2: D3.1 (K), D6.1 (K), D9.1 (K), U1.3 (PA10_A2_D2)
GND: J1.1, SW10.C, U1.13 (GND)
unnamed: D1.2 (A), SW1.2
unnamed: D2.2 (A), SW2.2
unnamed: D3.2 (A), SW3.2
unnamed: D4.2 (A), SW4.2
unnamed: D5.2 (A), SW5.2
unnamed: D6.2 (A), SW6.2
unnamed: D7.2 (A), SW7.2
unnamed: D8.2 (A), SW8.2
unnamed: D9.2 (A), SW9.2

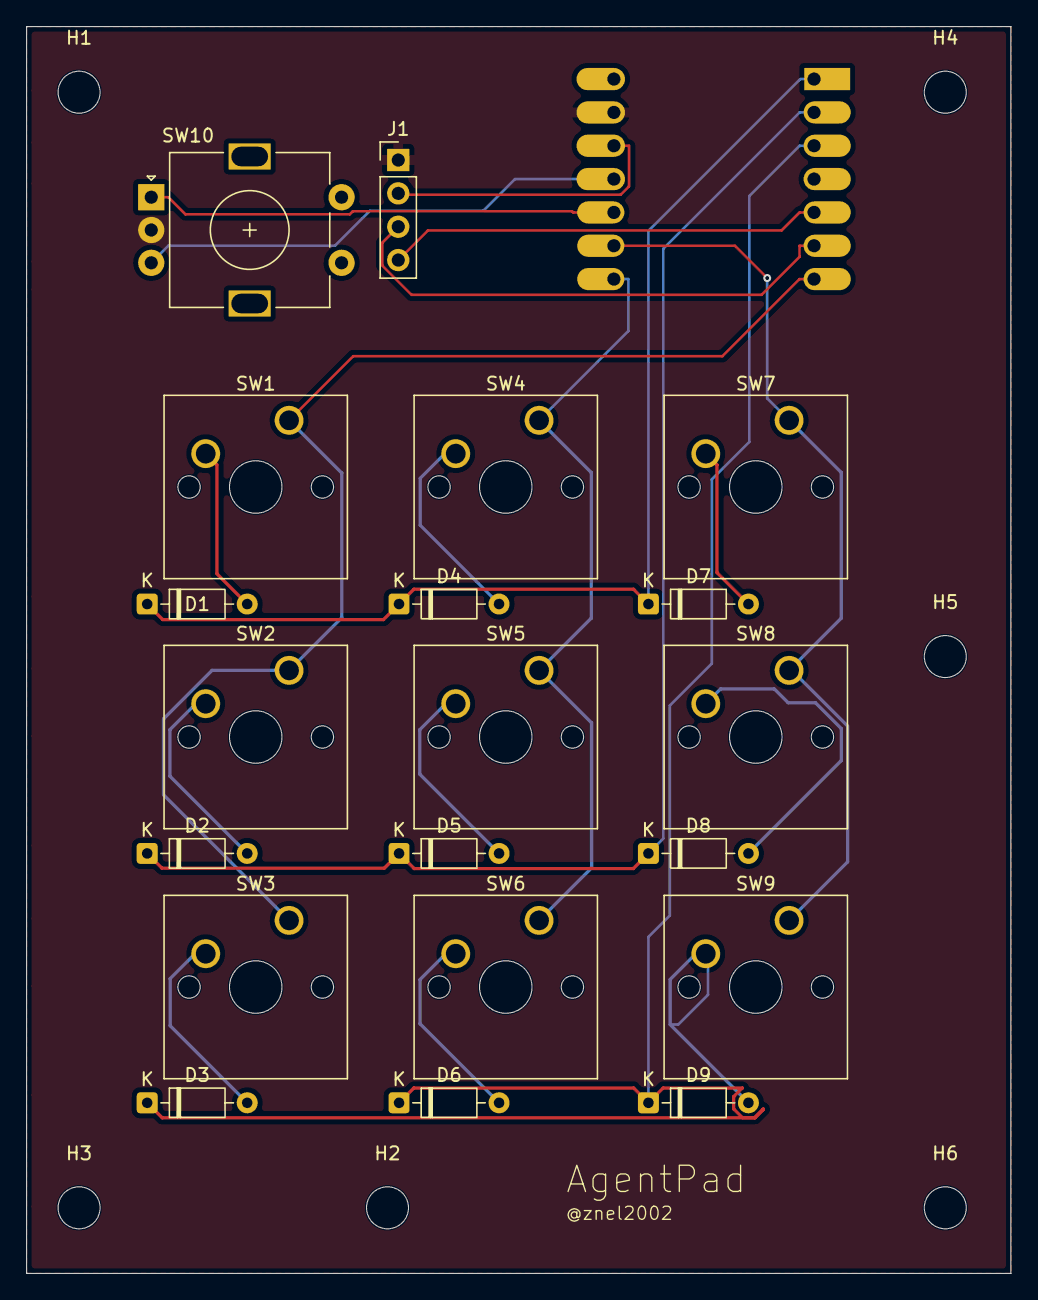
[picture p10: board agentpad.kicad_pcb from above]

Board: 2 copper layers, 75.0 x 95.0 mm, 27 parts (1 on the bottom side), 21 nets.

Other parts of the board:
H1, H2, H3, H4, H5, H6: MountingHole_3.2mm_M3

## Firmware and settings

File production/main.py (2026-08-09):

# AgentPad — KMK firmware skeleton
# 9-key (3x3) + 1 turn-only EC11 encoder + 0.91" OLED + 20x SK6812 RGB
# on a Seeed XIAO RP2040. Design: ../../docs/DESIGN-SPEC.md
#
# Copy to CIRCUITPY/main.py. See ../README.md for the KMK + library setup.
# This is a STARTING POINT: matrix/encoder/layers/RGB/OLED are wired up, but the
# per-tool keystrokes are placeholders you refine, and the layer-cycle key should
# be verified on your KMK version (note below).

import board

from kmk.kmk_keyboard import KMKKeyboard
from kmk.keys import KC, make_key
from kmk.matrix import DiodeOrientation
from kmk.modules.layers import Layers
from kmk.modules.holdtap import HoldTap
from kmk.modules.encoder import EncoderHandler
from kmk.handlers.sequences import send_string

keyboard = KMKKeyboard()

# ----------------------------------------------------------------------------
# Matrix  (net map in ../../PCB/README.md)
# ----------------------------------------------------------------------------
keyboard.row_pins = (board.D0, board.D1, board.D2)          # ROW0..2 (GP26/27/28)
keyboard.col_pins = (board.D6, board.D7, board.D8)          # COL0..2 (GP0/1/2)
keyboard.diode_orientation = DiodeOrientation.COL2ROW       # match the PCB diodes

# ----------------------------------------------------------------------------
# Modules
# ----------------------------------------------------------------------------
keyboard.modules.append(Layers())
keyboard.modules.append(HoldTap())
encoder = EncoderHandler()
keyboard.modules.append(encoder)

# ----------------------------------------------------------------------------
# Tool layers: 0 Claude Code | 1 Codex | 2 Cursor | 3 shell | 4 FN (hold LAYER)
# ----------------------------------------------------------------------------
CLAUDE, CODEX, CURSOR, SHELL, FN = 0, 1, 2, 3, 4

# LAYER key: tap = cycle the active tool layer; hold = momentary FN.
# NOTE: cycling isn't a built-in KMK keycode, so it's a custom key that rewrites
# active_layers. If it misbehaves on your KMK build, replace CYCLE with KC.MO(FN)
# and put KC.TO(0..3) on four FN-layer keys instead (rock-solid fallback).
_tool = [CLAUDE]


def _cycle_tool(key, keyboard, *args, **kwargs):
    _tool[0] = (_tool[0] + 1) % 4
    keyboard.active_layers[:] = [_tool[0]]


CYCLE = make_key(names=("CYCLE",), on_press=_cycle_tool)
LAYER = KC.HT(CYCLE, KC.MO(FN))     # tap=cycle tool, hold=FN

# send_string sequences for typed commands
CC_NEW = send_string("/clear\n")
CC_COMPACT = send_string("/compact\n")
CC_RESUME = send_string("/resume\n")
RUN_CMD = send_string("npm test\n")  # <- your test/last command

# Keymap: 9 keys row-major (R1C1,R1C2,R1C3, R2C1..). One row per layer.
keyboard.keymap = [
    # Layer 0 — Claude Code
    [
        KC.ESC,   KC.ENTER, KC.N,       # STOP  YES   NO
        KC.LSFT(KC.TAB), CC_NEW, KC.SPACE,  # PLAN  NEW   TALK(hold)
        RUN_CMD,  CC_COMPACT, LAYER,     # RUN   COMPACT  LAYER
    ],
    # Layer 1 — Codex (TODO: confirm current Codex TUI keys)
    [
        KC.ESC,   KC.ENTER, KC.TAB,      # STOP  steer  queue
        KC.LSFT(KC.TAB), send_string("/new\n"), KC.SPACE,
        RUN_CMD,  send_string("/compact\n"), LAYER,
    ],
    # Layer 2 — Cursor (GUI; Cmd-based. TODO: confirm)
    [
        KC.LGUI(KC.BSPC), KC.LGUI(KC.ENTER), KC.ESC,   # stop  accept-all  reject
        KC.NO,    KC.LGUI(KC.N), KC.SPACE,             # (no plan-mode)  new-chat  talk
        RUN_CMD,  KC.NO, LAYER,
    ],
    # Layer 3 — shell / generic terminal
    [
        KC.LCTL(KC.C), KC.ENTER, KC.LCTL(KC.C),        # SIGINT  enter  SIGINT
        KC.NO,    send_string("clear\n"), KC.SPACE,
        send_string("!!\n"), KC.NO, LAYER,             # RUN = repeat last cmd
    ],
    # Layer 4 — FN (held via LAYER). Hold-LAYER secondaries.
    [
        KC.TRNS,  KC.ENTER,  KC.ESC,     # -      accept-edit  reject-edit
        KC.TRNS,  CC_RESUME, KC.TRNS,    # -      resume       -
        KC.LCTL(KC.B), KC.TRNS, KC.TRNS, # background  -  (LAYER held)
    ],
]

# ----------------------------------------------------------------------------
# Encoder — turn-only effort/model dial. Placeholder = arrow up/down; remap per
# tool to its effort/model control once finalized. (ccw, cw) per encoder, per layer.
# ----------------------------------------------------------------------------
encoder.pins = ((board.D9, board.D10, None),)   # A, B, no push button
encoder.map = [
    ((KC.DOWN, KC.UP),),   # Claude Code
    ((KC.DOWN, KC.UP),),   # Codex
    ((KC.DOWN, KC.UP),),   # Cursor
    ((KC.DOWN, KC.UP),),   # shell
    ((KC.TRNS, KC.TRNS),),  # FN
]

# ----------------------------------------------------------------------------
# RGB — deferred to v2. The shipping v1 board has NO LEDs: the SK6812 reverse-mount
# footprint (with its built-in board cutout) fought DRC, and per-key/underglow RGB
# is not required by Hackpad (the reference board barely used LEDs). Data pin D3
# (XIAO pin 4) is left unused on v1. v2 will add a proper RGB footprint + this block.
# ----------------------------------------------------------------------------

# ----------------------------------------------------------------------------
# OLED — boot splash + status. Needs adafruit_displayio_ssd1306 in CIRCUITPY/lib.
# ----------------------------------------------------------------------------
try:
    from kmk.extensions.display import Display, TextEntry
    from kmk.extensions.display.ssd1306 import SSD1306

    display = Display(
        display=SSD1306(sda=board.SDA, scl=board.SCL, device_address=0x3C),
        entries=[
            TextEntry(text="AgentPad", x=0, y=0),
            TextEntry(text="CLAUDE CODE", x=0, y=12),
            TextEntry(text="effort: HIGH", x=0, y=24),
        ],
        width=128,
        height=32,
    )
    keyboard.extensions.append(display)
except Exception as exc:  # noqa: BLE001
    print("OLED init skipped:", exc)


if __name__ == "__main__":
    keyboard.go()

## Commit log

2026-08-08 Scaffold AgentPad: locked design spec, build plan, PCB net map, KMK firmware skeleton
    9-key (3x3) + 1 turn-only encoder + OLED + SK6812 RGB on XIAO RP2040, KMK-first,
    4 tool layers (Claude Code/Codex/Cursor/shell). Kit-only Config A.
2026-08-08 Wire in real Hackpad resources: care-package + footprint links, case dims, mounting-hole specs
    PCB/README: real care-package release URL, XIAO/MX/encoder/OLED footprint sources,
    orpheuspad reference, mounting-hole + routing tips. CAD/README: heatset (4.7mm x 4mm),
    0.2mm tolerance, +0.4mm PCB cutout, plate/base extrude dims, ai03 plate generator.
2026-08-08 Correct + complete PCB/case data from full Hackpad site read
    Fix: SK6812 VCC is 5V (not 3V3). Add exact symbols/footprints (diode DO-35 P7.62,
    RotaryEncoder_Switch / EC11E-Switch_Vertical_H20mm, SK6812MINI-E, OLED 4-pin header),
    LED notch orientation, no-pullups note. Assembly order (switches-in-plate-first,
    diode black-bar, e-test, serial). Flag grant $10-vs-$15 conflict + Germany shipping.
2026-08-08 Vendor Hack Club care package; pin exact library part names
    Care package (XIAO + SK6812 only) vendored in PCB/lib/. Corrected names verified
    against the unpacked files: symbol MOUDLE-SEEEDUINO-XIAO (typo is real), footprints
    XIAO-Generic-Hybrid-14P-2.54-21X17.8MM and SK6812MINI-E_fixed. Rest are KiCad built-ins.
2026-08-09 Add KiCad project + privacy cleanup for public release
    Schematic complete and ERC-clean (matrix + encoder + OLED + SK6812 chain).
    Strip personal vault references; gitignore KiCad local files + tutorial board.
    [agentpad.kicad_pcb, agentpad.kicad_sch]
2026-08-09 Complete v1 PCB (DRC 0 errors); drop LEDs, add gerbers.zip
    9-key matrix + encoder + OLED routed on 2 layers with dual GND planes, DRC clean.
    RGB deferred to v2 (SK6812 reverse-mount footprint failed edge-clearance DRC; not
    required by Hackpad). Firmware + design spec + README updated to match v1.
    [agentpad.kicad_pcb, agentpad.kicad_sch]
2026-08-09 Add host-side keymap simulator (functional test, no hardware)
    Verifies all 45 physical-key -> keystroke mappings across 5 layers, the LAYER
    tap-to-cycle, and the encoder. Guards against keymap-array reordering.
2026-08-09 Re-add 6 M3 mounting holes (were deleted with LEDs); refresh gerbers.zip
    The 'delete footprints with no symbols' step during LED removal also removed the
    mounting holes. Re-placed H1-H6 clear of keycaps; regenerated gerbers with holes.
    [agentpad.kicad_pcb]
2026-08-09 Add parametric OpenSCAD case (top plate + bottom tray)
    Generated from the extracted board geometry: 95x95, 6 heatset bosses at the
    mounting holes, 9 MX switch cutouts, encoder/OLED/USB cutouts (parametric,
    flagged for verification), recessed AgentPad branding.
    [agentpad_case.scad]
2026-08-09 Case: USB-C faces top (north), cut as inward channel to the recessed port
    XIAO pins are vertical columns -> USB on the top short edge, ~9mm inside the edge,
    so the cutout is a channel (usb_depth) not a wall slot. Narrow OLED window to clear
    the encoder.
    [agentpad_case.scad]
2026-08-10 Case: model real PCB + components in the assembly for a visual fit check
    Switches poke through the plate cutouts, encoder/OLED/keycaps, and the XIAO + USB-C
    on the back sit in the channel. Default to an assembled (nested) view; explode>0 separates.
    Fit verified numerically (holes/bosses, cutouts, USB channel, clearances) — all pass.
    [agentpad_case.scad]
2026-08-10 Case: fix plate Z in assembly (was buried in the tray); export real board STEP
    Assembly now shows the translucent top plate seated on the PCB with switches
    through the cutouts. Add CAD/agentpad-board.step (real 3D board) as a reference.
    [agentpad-board.step, agentpad_case.scad]
2026-08-10 Case: add realfit view — import the real KiCad board (STL) into the case
    Verified fit with the actual PCB: switch pads align with plate cutouts, 6 mounting
    holes align with tray bosses, OLED header + XIAO/USB positioned correctly. Board STL
    converted from STEP via FreeCAD; transform is a pure translate (STEP negates Y).
    [agentpad-board.stl, agentpad_case.scad]
2026-08-10 CAD/production complete: plate + tray STLs, real-board assembly 3MF, firmware
    Generated printable top_plate.stl + bottom_tray.stl (production/), and
    agentpad_assembly.3mf containing the real KiCad board inside the case. Copied
    KMK main.py into production/ per Hackpad's submission structure.
    [agentpad_assembly.3mf, bottom_tray.stl, top_plate.stl]
2026-08-10 Case: fix H5 mounting hole (48->47mm) to match the PCB; regenerate STLs + 3MF
    Verified mathematically: all 9 switch cutouts align to the real switches at 0.000mm
    (encoder/OLED 0.000 too); the grid is intentionally ~11.5mm off board-center because
    the XIAO/encoder/OLED occupy the left+top. Only real error was H5 (1mm) -> fixed.
    [agentpad_assembly.3mf, agentpad_case.scad, bottom_tray.stl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]
2026-08-10 Case: center cutouts on component centers, not footprint origins
    MX footprint origin sits on pin 1, not the stem, so cutouts were off by (2.54,5.08)mm
    (what looked 'off center'). Applied uniform stem offset; moved encoder hole to the
    shaft (+7.25mm) and OLED to its module center. Verified: all 9 cutouts 0.000mm to stems.
    [agentpad_assembly.3mf, agentpad_case.scad, top_plate.stl]
2026-08-10 Case: fix encoder + OLED cutouts to real geometry
    Encoder hole -> true shaft (mounting-post midpoint, origin+7.5,2.5). OLED window
    -> full module-length slot (~38mm) extending from the header (module mounts on the
    4-pin header and extends sideways), replacing the too-small header-centered window.
    [agentpad_assembly.3mf, agentpad_case.scad, top_plate.stl]
2026-08-10 Case: remove broken plate-top text; move AgentPad branding to tray underside
    Plate top is now clean (cutouts only). Branding recessed into the tray underside,
    mirrored so it reads when the case is flipped over — keeps Hackpad's 'case branded
    with the pad name' requirement satisfied without the messy top text.
    [agentpad_assembly.3mf, agentpad_case.scad, bottom_tray.stl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]
2026-08-10 Submission-ready README: overall render, schematic, PCB, exploded case + BOM
    All 5 Hackpad-required README elements. Images generated from source: case renders
    (OpenSCAD), PCB 3D render + schematic SVG (kicad-cli).
2026-08-10 Restyle case to Hackpad-v5 two-tone sandwich
    Red top plate with a raised perimeter bezel and recessed key well
    (no exposed PCB), black bottom tray, 6 mm rounded corners. Keycaps
    seat inside the well. Regenerated STLs, 3MF assembly, and README
    renders (assembled + exploded).
    [agentpad_assembly.3mf, agentpad_case.scad, bottom_tray.stl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]
2026-08-10 Fix assembly 3mf: restore real KiCad board inside the case
    The restyle regenerated the 3mf from part="assembly" (crude PCB
    placeholder), dropping the real board. Rebuilt from part="realfit"
    so agentpad_assembly.3mf again contains the imported board STL
    inside the two-tone case, matching the README's "real PCB + case".
    [agentpad_assembly.3mf]
2026-08-10 README: use high-res PNG schematic instead of SVG
    The SVG rendered hard to read on GitHub. Export a 300 DPI
    black-and-white PNG (3508x2481) via kicad-cli PDF + pdftoppm and
    reference it in the README. The schematic.svg source stays in the repo.
2026-08-10 PCB: add GND pour + silkscreen branding; regenerate fab outputs
    Board now has ground fill zones and 'AgentPad @znel2002' silkscreen
    branding. DRC: 0 errors (27 cosmetic silk warnings only). Regenerated
    gerbers.zip, board STEP, and the README PCB render.
    [agentpad-board.step, agentpad.kicad_pcb]
2026-08-10 Track PCB project-settings change; ignore Freerouting .rules artifact
2026-08-13 Rebuild case in Fusion: styled two-part sandwich, USB-C, branding
    Replace the OpenSCAD case with a Fusion-designed lid + base built around
    the real PCB (STEP import), cutouts verified on the actual switch stems.
    Lid: recessed key well, raised bezel, chamfered switch mouths, encoder +
    OLED cutouts, R6 corners. Base: PCB tray, USB-C side slot, 'AgentPad'
    engraved front wall, matching R6 corners + chamfer, 4 corner screws.
    Export top_plate/bottom_tray STL, assembly STEP + 3MF, and the .f3d
    source; regenerate assembled + exploded renders; update READMEs; drop
    the obsolete .scad and board STL.
    [agentpad-board-origin.step, agentpad-board.stl, agentpad-case.f3d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]
